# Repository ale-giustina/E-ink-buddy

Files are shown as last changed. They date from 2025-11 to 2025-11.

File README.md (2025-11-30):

# E-Ink buddy
A simple e-ink display that shows time, date, weather, and other useful information.
## Features
- Time and Date display
- 5 minute update option with led minute indicator or 1 minute update with second indicator
- Multiple tabs for different information
- Weather information and graphics
- 24h and 5-day weather forecast graphs
- Bus arrival times for specified stops

## Hardware
- HINK-E075A01-A8 7.5″ three-color (black/white/red) E‑Ink panel 640×385
   - Any compatible e-ink display should work with minor adjustments to the graphics library. It just needs to be supported by the GxEPD2 library.

- Good Display DESPI-C02 adapter board

- ESP32-wroom-32 CP2102 (any ESP32 board should work)

- 6 leds

- 3 capacitive buttons

- 3D printed case

## Wiring
Wiring Diagram
## Software
The project uses the following external libraries:
- GxEPD2 by ZinggJM
- Adafruit GFX by Adafruit
- ArduinoJson by Benoit Blanchon

The project itself is written using the arduino framework in PlatformIO.
## Architecture
The project is divided into several modules that each handle a specific functionality and communicates via structures.
Architecture Diagram

### graphics.cpp
Handles all graphics rendering on the e-ink display. It uses the GxEPD2 and Adafruit GFX libraries to draw text and images.
It also contains helper functions for rendering headers, graphs and other elements.

### weather.cpp
Handles fetching and parsing weather data from open-meteo.com. It retrieves current weather conditions and forecasts, and provides functions to get weather forecasts and data points for graphs.
All weather icons are stored as bitmaps in the `bitmaps.h` file.
For more information consult the header file that contains documentation for all functions and structures.

### tr_api.cpp
Handles fetching and parsing bus arrival times from the Trentino trasporti API. It retrieves upcoming bus times for specified stops and provides functions to get stop information and arrival times.
For more information consult the header file that contains documentation for all functions and structures.
Thanks to [trentino-trasporti-api](https://github.com/matteocontrini/trentino-trasporti-api) for the API documentation.
Sample API calls can be found in the `Sample_calls` folder, both for buses and weather.

### helpers.cpp
Contains various printing and debugging functions used throughout the project.

### main.cpp
The main application logic. It initializes the hardware and software components, handles user input, and manages the display updates.
It works with tasks to update different parts of the display in the background.
There is `the-timekeeper-task` that handles timekeeping and user input, and starts several other tasks for updating weather, bus times, and other information.
The tabs system is implemented as a pseudo finite-state machine, where each tab is a state that can be switched by user input.

## Images
Main screen with time, date, and small 24h weather graph in minute update mode:
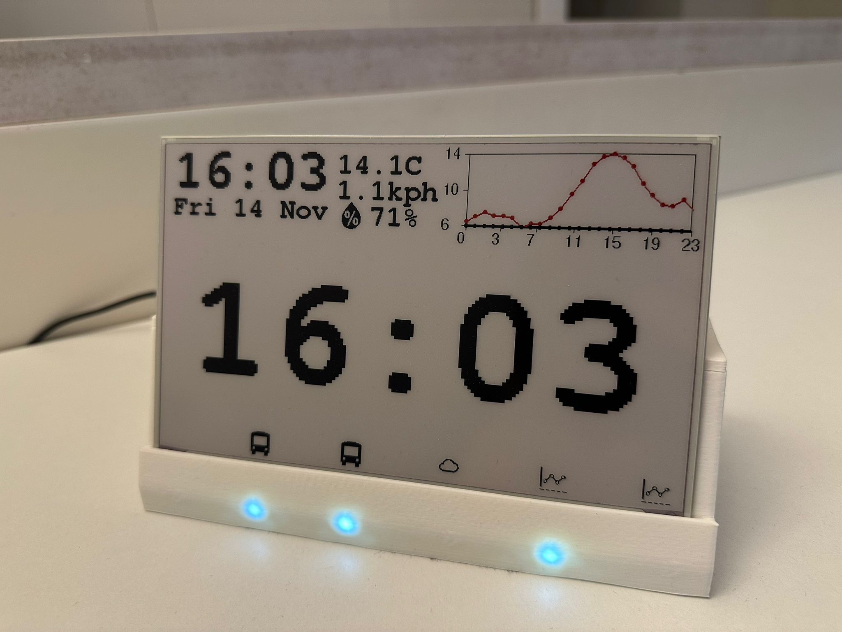
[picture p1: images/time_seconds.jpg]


Main screen with time, date, and led minute indicator in 5 minute update mode:
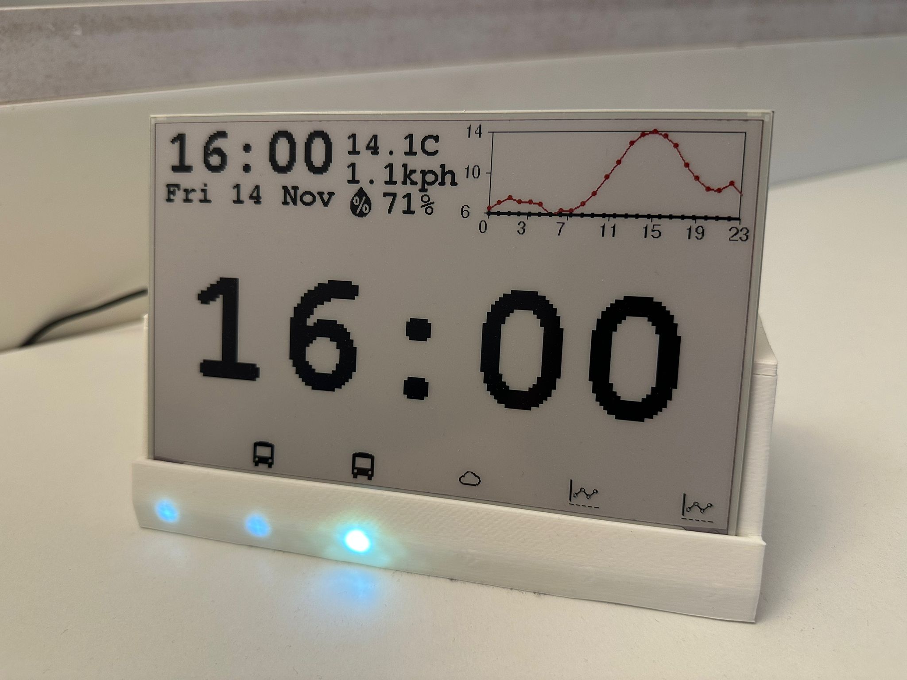
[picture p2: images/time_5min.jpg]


24h graph (it shows temperature, precipitation probability, cloud cover and humidity):
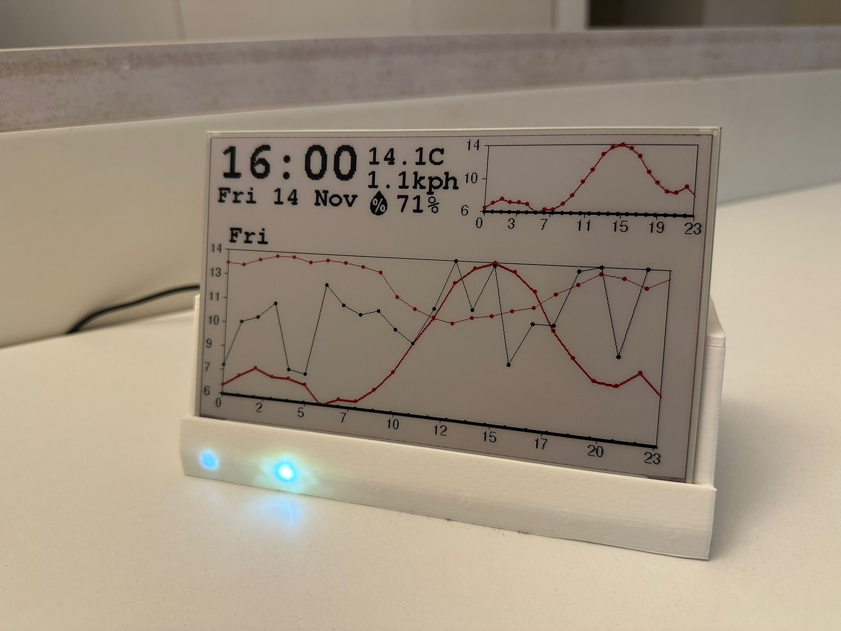
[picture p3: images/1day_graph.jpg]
24h Weather Forecast

The graph can be shifted up to 6 days into the future using the rear buttons:
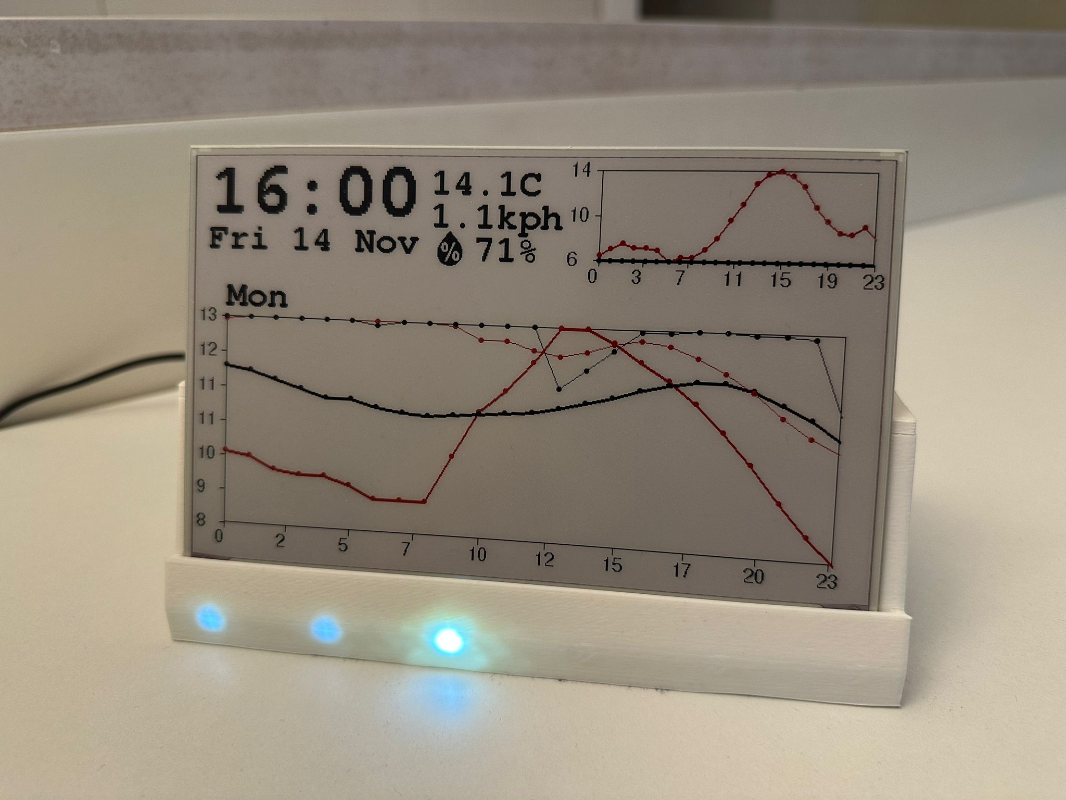
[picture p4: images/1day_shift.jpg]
24h Weather Forecast Future

5-day weather forecast graph (it shows hourly temperature and precipitation probability for the next 5 days, this can also be shifted using the rear buttons up to 6 days into the future):
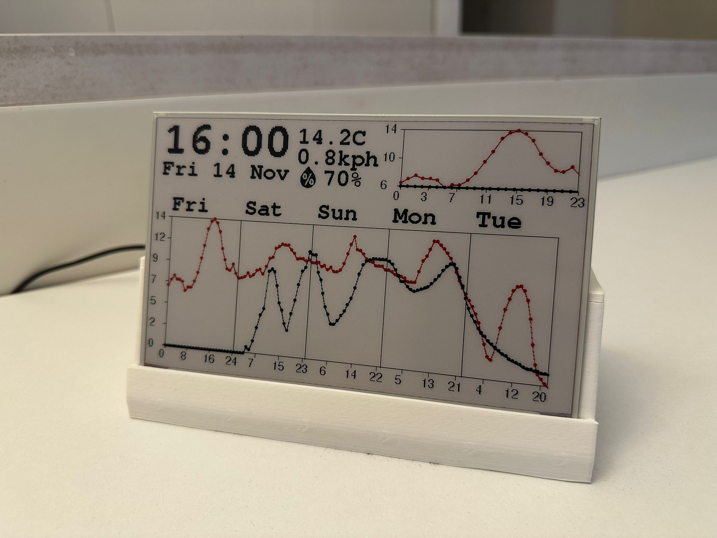
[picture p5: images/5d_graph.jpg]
5-day Weather Forecast

6 day weather forecast tab (shows daily high/low temperature, precipitation probability and weather icons for the next 6 days):
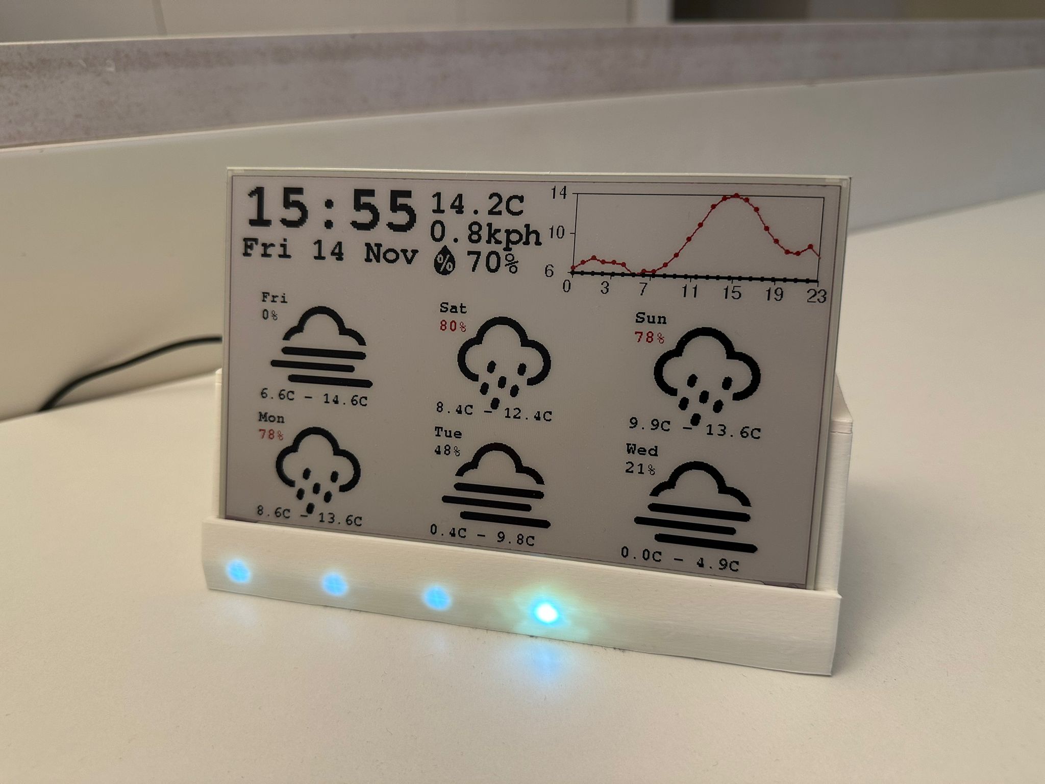
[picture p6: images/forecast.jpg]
6-day Weather Forecast

Non filtered bus arrival times for a specified stop (the list can be scrolled using the rear buttons):
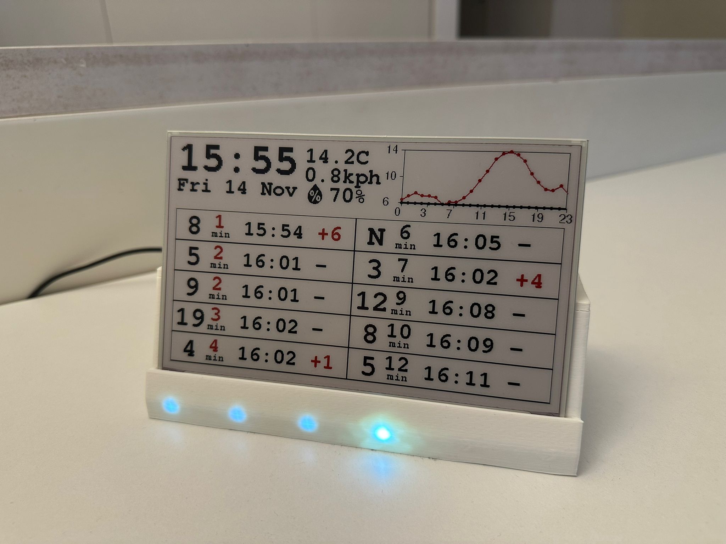
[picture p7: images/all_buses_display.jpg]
Bus Arrival Times

Filtered bus arrival times for a specified stop (only the bus number 5 is shown):
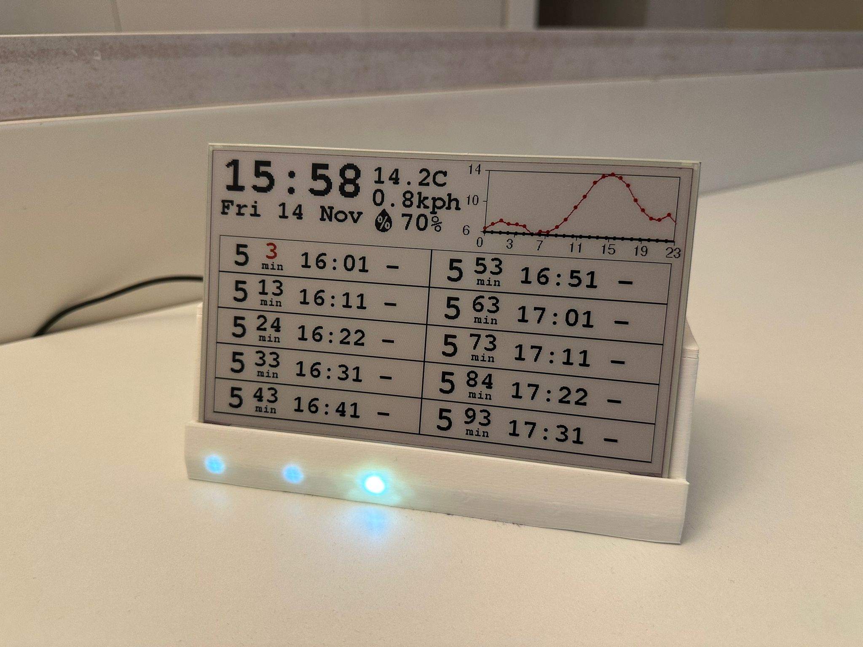
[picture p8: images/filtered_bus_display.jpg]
Filtered Bus Arrival Times

The awful prototyping wiring:
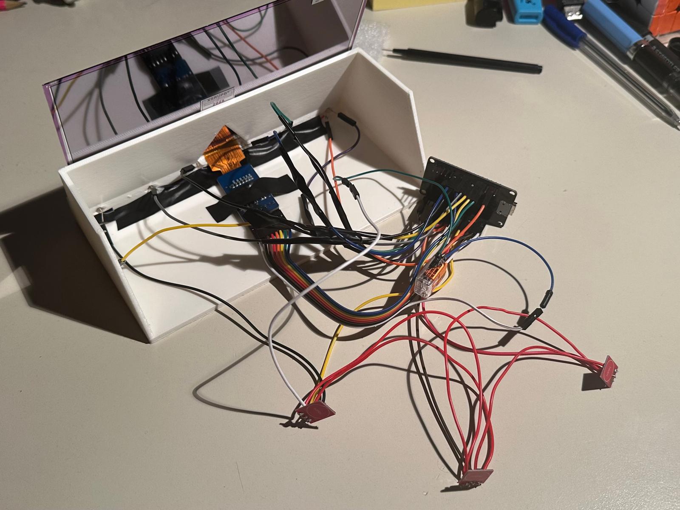
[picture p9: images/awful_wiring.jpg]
Wiring

Bitmaps taken from [weather-icons](https://github.com/erikflowers/weather-icons/tree/master?tab=readme-ov-file). 
<br>Thanks again to [trentino-trasporti-api](https://github.com/matteocontrini/trentino-trasporti-api) for the API documentation.

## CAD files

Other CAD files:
Models/E-paper_v3.f3d

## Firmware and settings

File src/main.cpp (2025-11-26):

// Author: Alessandro Giustina
// Description: Main application file

#include <Arduino.h>
#include "secrets.h"
#include <WiFi.h>
#include <HTTPClient.h>
#include <tr_api.h>
#include <time.h>
#include <weather.h>
#include <helpers.h>
#include <graphics.h>

// Pin definitions
const int led_pins[] = {22, 21, 32, 33, 26, 27};
const int input_pins[] = {15,2,4};

// Global structures
Weather_5D buf_5d;
Weather_24H buf_24h;
Weather_now buf_now;

// Mutexes for thread safety
SemaphoreHandle_t weather_mutex;
SemaphoreHandle_t route_mutex;

// Route information (10 + 6 that can be shifted)
#define MAX_ROUTES 16
RouteInfo info_SMM[MAX_ROUTES];
RouteInfo info_SMM_filtered[MAX_ROUTES];

// Machine states
enum machine_state{
  DEFAULT_CLOCK, DAY_FORECAST_5, BUS_ARRIVALS_5, BUS_ARRIVALS, GRAPH_5_DAYS, GRAPH_24_H
};
machine_state m_state;


// Selector for shifting routes
int shift_selector = 0;

// Graphics update flags
volatile bool graphics_update_in_progress = false;
volatile bool graphics_update_requested = false;

// Five minute display mode flag
volatile bool five_min_display_mode = false;

// Task declarations
void the_timekeeper_tsk(void * parameter);
void api_update_tsk(void * parameter);
void renderer_tsk(void * parameter);
void check_wifi_connection(void * parameter);
void modify_leds(void * parameter);

void setup() {

  // Initial state
  m_state = DEFAULT_CLOCK;

  start_graphics();
  
  // Display startup image
  do{
    display.fillScreen(GxEPD_BLACK);
    display.drawBitmap(D_WIDTH/2 - 75, D_HEIGHT/2 - 75, epd_bitmap_allArray[15], 150, 150, GxEPD_WHITE);
  }while(display.nextPage());

  // Initialize serial communication
  Serial.begin(115200);

  // Connect to WiFi
  WiFi.begin(WIFI_SSID, WIFI_PASSWORD);
  while (WiFi.status() != WL_CONNECTED) {
    delay(1000);
    Serial.println("Connecting to WiFi...");
  }
  Serial.println("Connected to WiFi");

  // Disable debug mode
  enable_debug = false;

  // Create route map
  while(!create_route_map()){
    vTaskDelay(1000 / portTICK_PERIOD_MS);
  };

  // Initialize LED pins
  for(int i : led_pins){
    pinMode(i, OUTPUT);
  }
  for(int i : input_pins){
    pinMode(i, INPUT);
  }

  // Configure timezone and NTP servers
  configTzTime("CET-1CEST-2,M3.5.0/2,M10.5.0/3", "pool.ntp.org");

  // Create mutexes
  weather_mutex = xSemaphoreCreateMutex();
  route_mutex = xSemaphoreCreateMutex();

  // Start first API update task
  xTaskCreate(api_update_tsk, "API Update Task", 12288, NULL, 1, NULL);

  vTaskDelay(8000 / portTICK_PERIOD_MS);

  // Start renderer task
  xTaskCreate(renderer_tsk, "Renderer Task", 8192, NULL, 1, NULL);

  vTaskDelay(8000 / portTICK_PERIOD_MS);

  // Start timekeeper task
  xTaskCreate(the_timekeeper_tsk, "Timekeeper Task", 8192, NULL, 1, NULL);
  
}

void api_update_tsk(void * parameter){
  
  Serial.println("API Update Task started");

  if(xSemaphoreTake(weather_mutex, portMAX_DELAY)==pdTRUE){
    get_weather_5d(buf_5d);
    Serial.println("Fetched 5-day weather");
    get_weather_24h(buf_24h);
    Serial.println("Fetched 24-hour weather");
    get_current_weather(buf_now);
    Serial.println("Fetched current weather");
    xSemaphoreGive(weather_mutex);
  }
  
  Serial.println("Done weather, fetching route info...");
  
  if(xSemaphoreTake(route_mutex, portMAX_DELAY)==pdTRUE){
    get_stop_info(247, info_SMM, MAX_ROUTES);
    get_stop_info_filtered(247, info_SMM_filtered, MAX_ROUTES, 400, false, true);// 247 piazza dante, 407 SMM
    xSemaphoreGive(route_mutex);
  }

  debug_println("==========================", true);
  debug_print_routes(info_SMM, MAX_ROUTES, true);
  debug_println("==========================", true);
  debug_print_routes(info_SMM_filtered, MAX_ROUTES, true);
  debug_println("==========================", true);

  debug_print_weather_5d(buf_5d, true);
  debug_println("==========================", true);
  debug_print_weather_24h(buf_24h, true);
  debug_println("==========================", true);
  debug_print_weather_now(buf_now, true);
  debug_println("==========================", true);
 
  vTaskDelete(NULL);

}

void renderer_tsk(void * parameter){
  graphics_update_in_progress = true;
  graphics_update_requested = false;
  Serial.print("Rendering... ");
  Serial.printf("Free heap:  %u\n", esp_get_free_heap_size());
  display.firstPage();
  
  // Call functions based on current state
  do {
    struct tm timeinfo;
    getLocalTime(&timeinfo);
    
    if(xSemaphoreTake(weather_mutex, portMAX_DELAY)==pdTRUE){
      draw_time_strip(0, 0, timeinfo, buf_now, &buf_24h, five_min_display_mode);
      xSemaphoreGive(weather_mutex);
    }
    if(m_state == GRAPH_24_H){
      if(xSemaphoreTake(weather_mutex, portMAX_DELAY)==pdTRUE){
        draw_24_h_graphs(buf_24h, timeinfo, shift_selector);
        xSemaphoreGive(weather_mutex);
      }
    }
    else if(m_state == DAY_FORECAST_5){
      if(xSemaphoreTake(weather_mutex, portMAX_DELAY)==pdTRUE){
        draw_5_day_forecast(buf_5d, timeinfo, shift_selector);
        xSemaphoreGive(weather_mutex);
      }
    }
    else if(m_state == BUS_ARRIVALS_5){
      if(xSemaphoreTake(route_mutex, portMAX_DELAY)==pdTRUE){
        draw_bus_arrivals(info_SMM_filtered, MAX_ROUTES, shift_selector);
        xSemaphoreGive(route_mutex);
      }
    }
    else if(m_state == BUS_ARRIVALS){
      if(xSemaphoreTake(route_mutex, portMAX_DELAY)==pdTRUE){
        draw_bus_arrivals(info_SMM, MAX_ROUTES, shift_selector);
        xSemaphoreGive(route_mutex);
      }
    }
    else if(m_state == GRAPH_5_DAYS){
      if(xSemaphoreTake(weather_mutex, portMAX_DELAY)==pdTRUE){
        draw_5_day_graphs(buf_5d, timeinfo, shift_selector);
        xSemaphoreGive(weather_mutex);
      }
    }
    else if(m_state == DEFAULT_CLOCK){
      draw_big_time(timeinfo, five_min_display_mode);
    }

  } while (display.nextPage());
  graphics_update_in_progress = false;
  vTaskDelete(NULL);

}

void check_wifi_connection(void * parameter){
  if(!is_connected()){
    Serial.println("WiFi disconnected, attempting reconnection...");
    WiFi.disconnect();
    WiFi.reconnect();
    unsigned long startAttemptTime = millis();
    // Wait for connection for 10 seconds
    while (WiFi.status() != WL_CONNECTED && millis() - startAttemptTime < 10000) {
      delay(500);
      Serial.print(".");
    }
    if(WiFi.status() == WL_CONNECTED){
      Serial.println("Reconnected to WiFi");
    }
    else{
      Serial.println("Failed to reconnect to WiFi");
    }
  }
  else{
    Serial.println("Wifi is fine");
  }
  vTaskDelete(NULL);
}

bool isChoosingShift = false;
bool pressedShift = false;

bool isChoosingStates = false;
bool pressedStates = false;

int wait_second = 0;
int old_secs = -1;
bool update_leds = false;

void modify_leds(void * parameter){

  machine_state working_states[] = {DEFAULT_CLOCK, BUS_ARRIVALS_5, BUS_ARRIVALS, DAY_FORECAST_5, GRAPH_5_DAYS, GRAPH_24_H};

  int secs = *((int*)parameter);

  // Toggle five minute display mode
  if(digitalRead(input_pins[2])){
    five_min_display_mode = !five_min_display_mode;
    graphics_update_requested = true;
    vTaskDelay(500 / portTICK_PERIOD_MS);
  }

  // Handle shift selection input
  if(digitalRead(input_pins[1])){
    isChoosingShift = true;
    isChoosingStates = false;
    if(!pressedShift){
      Serial.println(shift_selector);
      shift_selector+=1;
      shift_selector=shift_selector%7;
      update_leds=true;
    }
    pressedShift=true;
    wait_second = (secs+3)%60;
  }
  else{
    pressedShift=false;
  }

  // Handle state selection input
  if(digitalRead(input_pins[0])){
    isChoosingStates = true;
    isChoosingShift = false;
    if(!pressedStates){
      int current_state_index = 0;
      for(int i = 0; i<sizeof(working_states)/sizeof(machine_state); i++){
        if(m_state == working_states[i]){
          current_state_index = i;
        }
      }
      shift_selector = 0;
      current_state_index+=1;
      current_state_index=current_state_index%(sizeof(working_states)/sizeof(machine_state));
      m_state = working_states[current_state_index];
      Serial.print("Changed state to ");
      Serial.println(m_state);
      update_leds=true;

    }
    wait_second = (secs+3)%60;
    pressedStates=true;
  }
  else{
    pressedStates=false;
  }

  // Exit selection visualization after timeout
  if(secs == wait_second){
    isChoosingShift=false;
    isChoosingStates=false;
    wait_second = -1;
    graphics_update_requested = true;
  }

  // Update LEDs based on current selection
  if(isChoosingShift){
    if(update_leds){
      for(int i = 0; i<=5; i++){
        if(i<shift_selector){
          analogWrite(led_pins[i], 200);
        }
        else{
          analogWrite(led_pins[i], 0);
        }
      }
      update_leds=false;
    }
  }
  else if(isChoosingStates){
    if(update_leds){
      int state_index = 0;
      for(int i = 0; i<sizeof(working_states)/sizeof(machine_state); i++){
        if(m_state == working_states[i]){
          state_index = i;
        }
      }
      for(int i = 0; i<=5; i++){
        if(i==state_index){
          analogWrite(led_pins[i], 200);
        }
        else{
          analogWrite(led_pins[i], 0);
        }
      }
      update_leds=false;
    }
  }
  else{
    
    if(secs!=old_secs){
      old_secs=secs;
      // Update LEDs based on seconds
      if(!five_min_display_mode){
        for(int i = 5; i>=0; i--){
          //Serial.print(secs&0b1);
          if(secs&0b1){
            analogWrite(led_pins[i], 20);
          }
          else{
            analogWrite(led_pins[i], 0);
          }
          secs=secs>>1;
        }
      }
      else{
        struct tm timeinfo;
        getLocalTime(&timeinfo);
        //analogWrite(led_pins[5], secs); //If you want to show seconds with the sixth LED

        // Update LEDs based on minutes
        analogWrite(led_pins[5], 0); 
        for(int i = 5; i>=0; i--){
          
          if(i==timeinfo.tm_min%5){
            if(i-1>=0) analogWrite(led_pins[i-1], 100);
          }
          else if(i<timeinfo.tm_min%5){
            if(i-1>=0) analogWrite(led_pins[i-1], 10);
          }
          else{
            if(i-1>=0) analogWrite(led_pins[i-1], 0);
          }

        }
      }
    }
  }

}

void the_timekeeper_tsk(void * parameter){

  struct tm prev_sec;
  struct tm now;
  getLocalTime(&prev_sec);

  for(;;){
    getLocalTime(&now);

    // Check for time anomalies and restart if detected
    if(now.tm_sec > prev_sec.tm_sec+4 && now.tm_min == prev_sec.tm_min && now.tm_hour == prev_sec.tm_hour){
      WiFi.disconnect();
      ESP.restart();
    }

    // Handle tasks based on the current second
    if(now.tm_sec != prev_sec.tm_sec){
      prev_sec = now;
      // At 30 seconds, update API data
      if(now.tm_sec == 30){
        xTaskCreate(api_update_tsk, "API Update Task", 12288, NULL, 1, NULL);
      }
      // Every minute, request graphics update if in default clock mode
      else if((now.tm_sec == 0 || graphics_update_requested) && !graphics_update_in_progress && !isChoosingShift && !isChoosingStates && !five_min_display_mode){
        xTaskCreate(renderer_tsk, "Renderer Task", 8192, NULL, 1, NULL);
      }
      // At 15 seconds, check WiFi connection
      else if(now.tm_sec == 15){
        xTaskCreate(check_wifi_connection, "WiFi Check Task", 4096, NULL, 1, NULL);
      }
      // Every five minutes, update graphics in five minute display mode
      else if(((now.tm_min % 5 == 0 && now.tm_sec == 0) ||graphics_update_requested) && !graphics_update_in_progress && !isChoosingShift && !isChoosingStates && five_min_display_mode){
        xTaskCreate(renderer_tsk, "Renderer Task", 8192, NULL, 1, NULL);
      }
      
      Serial.println(String("Timekeeper: ")+String(now.tm_hour)+":"+String(now.tm_min)+":"+String(now.tm_sec));

    }
    // Update LEDs
    modify_leds((void*)&now.tm_sec);

  }

}

// Not needed
void loop() {

  vTaskDelete(NULL);

}

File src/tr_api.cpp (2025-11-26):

// Author: Alessandro Giustina
// Description: Transit API interaction implementation file

#include <tr_api.h>


std::map<int, std::array<String, 2>> routeMap;  // Global route map


static char buffer[BUFFER_SIZE]; // Global buffer for reading HTTP stream data

/**
 * @brief Reads the HTTPClient stream into a buffer, handling chunked transfer encoding.
 * @param client The HTTPClient instance to read from.
 * @param ignore_lists If true, ignores JSON lists in the stream. (used in the unfiltered mode)
 * @return The number of bytes read into the buffer.
 * 
 * This function reads data from the HTTPClient's stream, handling chunked transfer encoding.
 * It populates a global buffer with the received data and returns the total number of bytes read.
 * This is needed as the incoming data stream is sent in chunks formatted as <size>\r\n<data>\r\n.
 * The function continues reading until it encounters a chunk size of 0, indicating the end of the stream.
 */
int read_stream_to_buffer(HTTPClient &client, bool ignore_lists=false){
  
  WiFiClient& stream = client.getStream();
      
  char siz_buf[10];
  int index_buff = 0;
  int index_siz = 0;
  bool isPayload = false;
  char c;
  bool isList = false;
  while(true){
    
    // Wait until data is available
    while(!stream.available()){
      vTaskDelay(10 / portTICK_PERIOD_MS);
    }
    
    c = stream.read();
    if(c == '\r') continue;
    if(c == EOF) break;
    // Every chunk starts with a size line starting and ending with \n
    if(c == '\n'){
      isPayload = !isPayload;
      continue;
    }

    // Look for lists
    if(index_buff>10){
      if(ignore_lists && c == '[') isList = true;
      if(ignore_lists && c == ']' && isList) {
        isList = false;
        buffer[index_buff++] = '[';
      }
      if(ignore_lists && isList) continue;

    }

    // If the chunk size is zero, the stream has ended
    if(!isPayload){
      siz_buf[index_siz++] = c;
      if(siz_buf[0] == '0'){
        break;
      }
    }
    else{ // Else write in buffer
      buffer[index_buff++] = c;
      index_siz = 0;
    }
    
    // Clean up unwanted fields to reduce buffer size

    // ignore "tripId":"0004373042025091020260610"
    if(memcmp(buffer + index_buff - 36, "\"tripId\":", 9) == 0) {
      index_buff -= 37;
    }

    //"oraArrivoEffettivaAFermataSelezionata": null,
    //"oraArrivoProgrammataAFermataSelezionata": null,
    //"corsaPiuVicinaADataRiferimento": false,
    if (index_buff >= 44 && memcmp(buffer + index_buff - 44, "\"oraArrivoEffettivaAFermataSelezionata\":null,", 44) == 0) {
      index_buff -= 45;
    }

    if (index_buff >= 50 && memcmp(buffer + index_buff - 46, "\"oraArrivoProgrammataAFermataSelezionata\":null,", 46) == 0) {
      index_buff -= 47;
    }

    if (index_buff >= 40 && memcmp(buffer + index_buff - 38, "\"corsaPiuVicinaADataRiferimento\":false,", 38) == 0) {
      index_buff -= 39;
    }

    // "departureTime":"XX:XX:XX",
    if (index_buff >= 28 && memcmp(buffer + index_buff - 28, "\"departureTime\":", 16) == 0) {
      index_buff -= 27;
    }

    // "type":"U",
    if (index_buff >= 28 && memcmp(buffer + index_buff - 10, "\"type\":\"U\",", 10) == 0) {
      index_buff -= 11;
    }

    //stopSequenc
    if (index_buff >= 20 && memcmp(buffer + index_buff - 10, "stopSequenc", 10) == 0) {
      index_buff -= 10;
    }

    // Check for buffer overflow
    if(index_buff >= BUFFER_SIZE-1){
      debug_println("Buffer overflow!");
      break;
    }
  };
  // Null-terminate the buffer and return the size
  buffer[index_buff] = '\0';
  return index_buff;
}

// Create route map from API to map ID to names
bool create_route_map(){

  bool success = true;

  HTTPClient routeClient;
  String url = String(TT_BASE_URL) + "/routes?areas=23"; // Routes in Trento area
  routeClient.begin(url);
  routeClient.setAuthorization(TT_USER, TT_PASS);
  int httpCode = routeClient.GET();

  if (httpCode == 200) {

    String payload = routeClient.getString();

    JsonDocument doc;
    
    if (!deserializeJson(doc, payload)) {
      
      JsonArray arr = doc.as<JsonArray>();

      for (JsonObject elem : arr) {
        debug_print(elem["routeId"].as<String>());
        debug_print(" - ");
        debug_print(elem["routeShortName"].as<String>());
        debug_print(" - ");
        debug_println(elem["routeLongName"].as<String>());
        
        int routeId = elem["routeId"].as<int>();
        const char* shortName = elem["routeShortName"];
        const char* longName = elem["routeLongName"];
        String info[2] = {String(shortName), String(longName)};
        if (shortName != nullptr) {
          routeMap[routeId][0] = info[0];
          routeMap[routeId][1] = info[1];
        }
      }
      Serial.printf("Loaded %d routes\n", (int)routeMap.size());
      success = true;
    } else {
      Serial.println("Failed to parse routes JSON");

      success = false;
    }
  } else {
    Serial.printf("Failed to fetch routes, HTTP code: %d\n", httpCode);
    success = false;
  }
  routeClient.end();
  return success;
}
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

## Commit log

2025-11-02 Started work on filtering
2025-11-03 Added filtering by routeId
2025-11-05 Added led updates skeleton
2025-11-05 fixed incomplete input up to 10 trips
    [main.cpp, tr_api.cpp]
2025-11-10 Added startup screen and fixed daily graph
    [main.cpp]
2025-11-11 Added shift button functionality
2025-11-12 Fixed scene changer bug
    [main.cpp]
2025-11-26 chore: added wiring diagram
2025-11-30 Added 3d files
    [E-paper v3.f3d]
2025-11-30 chore: renamed model
    [E-paper_v3.f3d]
2025-11-30 Add image of 3D printed case to README
    Updated README to include a 3D printed case image.
